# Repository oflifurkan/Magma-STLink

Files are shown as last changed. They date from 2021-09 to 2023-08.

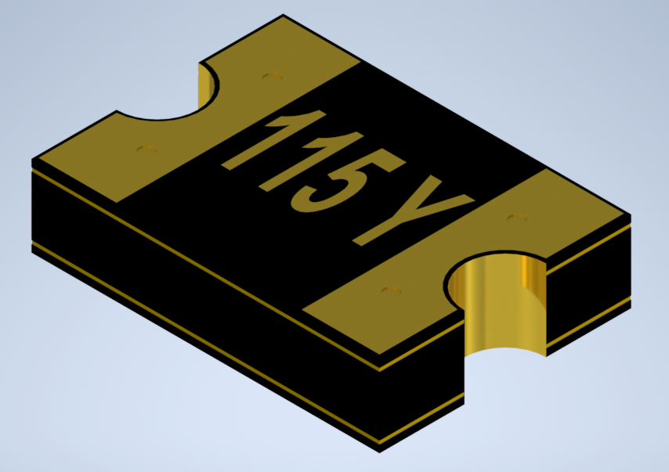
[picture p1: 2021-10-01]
Component Documents/Fuse 1812/smd-1812-pptc-multifuse-mf-1.snapshot.2/smd1812.bmp

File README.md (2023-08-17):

MAGMA STLink
============

STLink V2 design that I designed in KiCAD as a hobby for programming STM32 and STM8 microcontrollers

## What's required? 

* STM32F103C8 - with STLink V2 firmware
* 8 Mhz Crystal

* LM1117 - 5V to 3.3V LDO

* USB A Connector
* PTC Fuse
* Couple of 0805 package capacitors and resistor  

## CAD Software

* The latest KiCAD version

## Images
Magma_STLink_front
Magma_STLink_rear

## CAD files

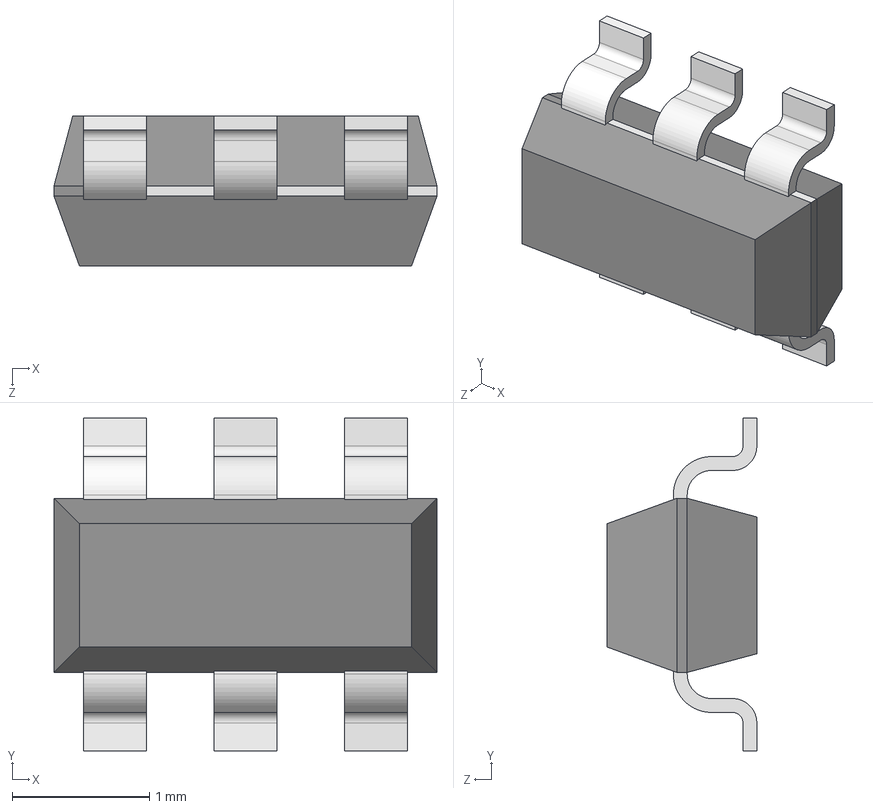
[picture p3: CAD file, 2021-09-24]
Component Documents/ESDA6V1BC6/User Library-SOT-23-6.STEP
2.79 x 2.43 x 1.09 mm

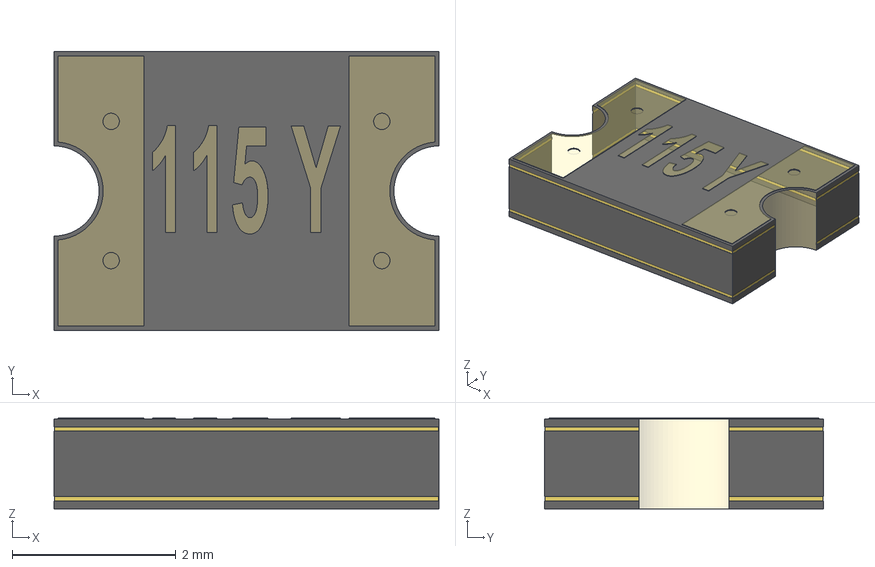
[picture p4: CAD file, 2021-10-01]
Component Documents/Fuse 1812/smd-1812-pptc-multifuse-mf-1.snapshot.2/smd1812.stp
4.70 x 3.40 x 1.11 mm

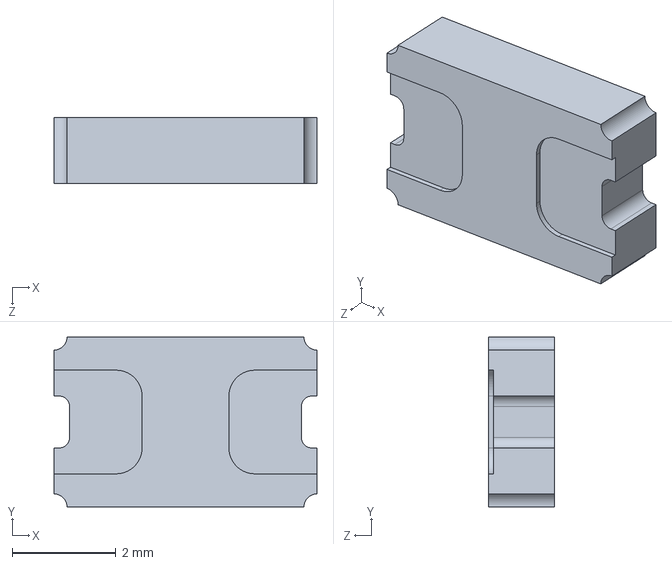
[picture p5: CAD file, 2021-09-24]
Component Documents/TXC 7A/TXC7A.STEP
5.08 x 3.28 x 1.28 mm

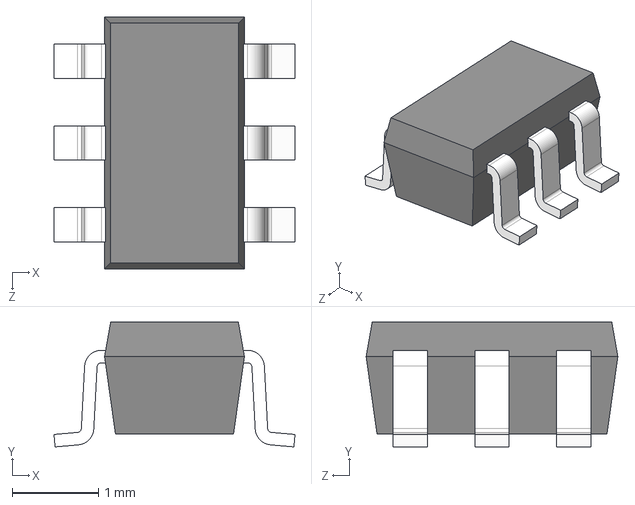
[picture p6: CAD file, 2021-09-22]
Component Documents/ESDA6V1BC6/ESDA6V1BC6.step
2.80 x 1.45 x 2.92 mm

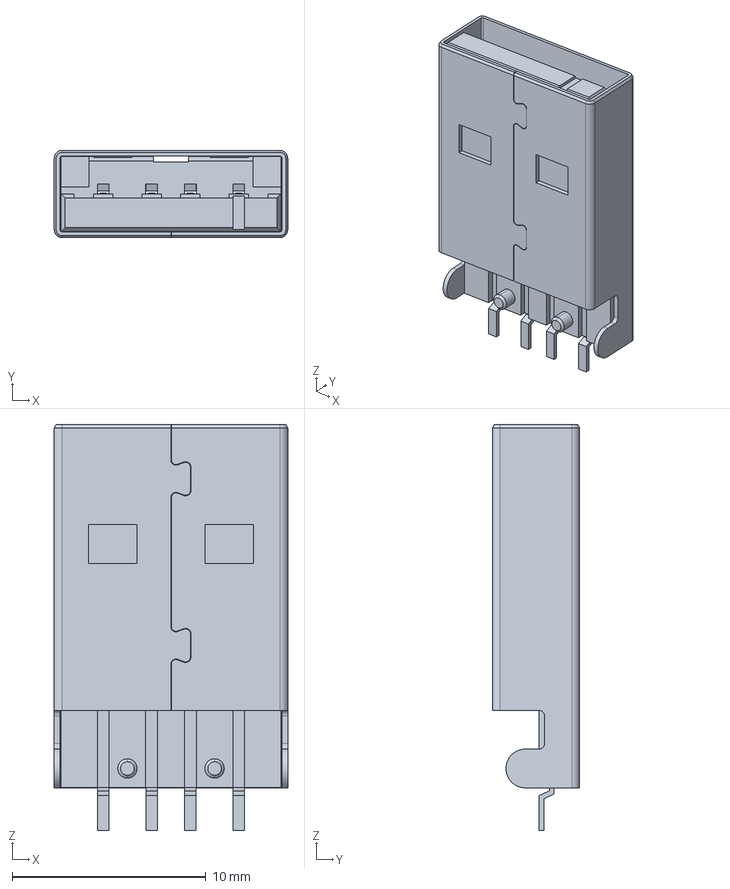
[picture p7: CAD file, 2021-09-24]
Component Documents/USB Type A Male Plug/48037-2200_stp/480372200.stp
12.1 x 4.50 x 21.0 mm

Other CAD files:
Component Documents/TXC 7A/TXC7A.SLDPRT

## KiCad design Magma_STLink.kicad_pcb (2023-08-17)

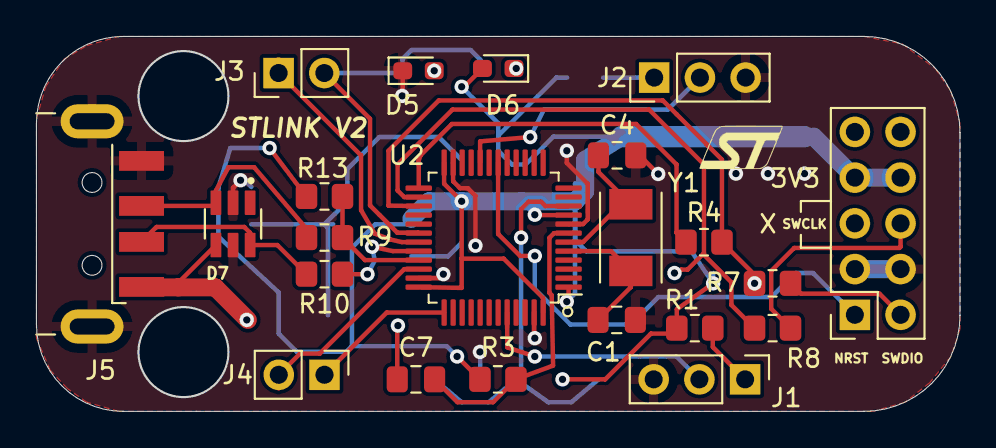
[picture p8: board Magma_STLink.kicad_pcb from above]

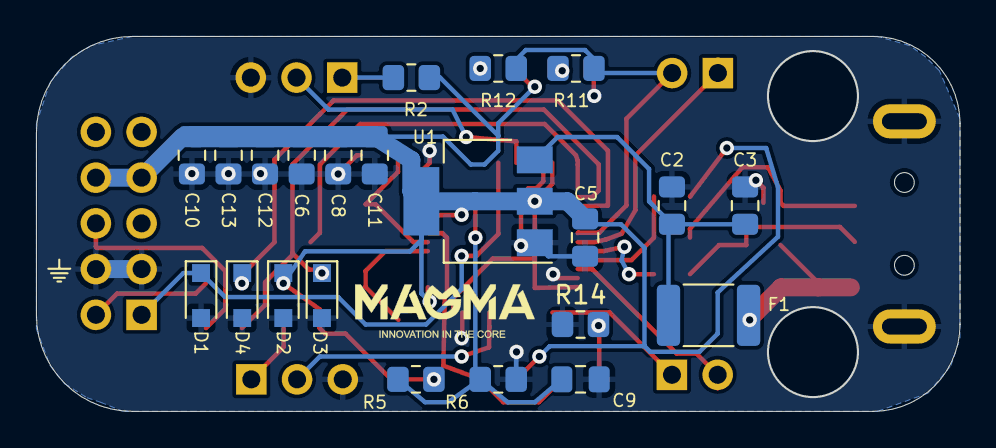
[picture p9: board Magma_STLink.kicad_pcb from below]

Board: 2 copper layers, 51.3 x 20.8 mm, 44 parts (22 on the bottom side), 29 nets.

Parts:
C1, C4: 18pF; C_0805_2012Metric_Pad1.18x1.45mm_HandSolder
C2, C5: 10uF; C_0805_2012Metric_Pad1.18x1.45mm_HandSolder
C3, C6, C7, C8, C9, C10, C11, C12, C13: 100nF; C_0805_2012Metric_Pad1.18x1.45mm_HandSolder
D1, D2, D3, D4: PESD3V3L1BA,115; D_SOD-323_HandSoldering
D5: RED LED; LED_0603_1608Metric_Pad1.05x0.95mm_HandSolder
D6: BLUE RED; LED_0603_1608Metric_Pad1.05x0.95mm_HandSolder
D7: ESDA6V1BC6; SOT95P280X145-6N
F1: 8V 2A; Fuse_1812_4532Metric_Pad1.30x3.40mm_HandSolder
J1, J2: Conn_01x03; PinHeader_1x03_P2.54mm_Vertical
J3, J4: Conn_01x02; PinHeader_1x02_P2.54mm_Vertical
J5: USB_A; USB_A_CNCTech_1001-011-01101_Horizontal
R1, R2: 10K; R_0805_2012Metric_Pad1.20x1.40mm_HandSolder
R3, R5, R6, R13, R14: 100K; R_0805_2012Metric_Pad1.20x1.40mm_HandSolder
R4: 220R; R_0805_2012Metric_Pad1.20x1.40mm_HandSolder
R7, R8, R9, R10: 75R; R_0805_2012Metric_Pad1.20x1.40mm_HandSolder
R11, R12: 200; R_0805_2012Metric_Pad1.20x1.40mm_HandSolder
STLINK_CONN1: STLINK CONN; PinSocket_2x05_P2.54mm_Vertical
U1: LM1117-3.3; SOT-223-3_TabPin2
U2: STM32F103C8Tx; LQFP-48_7x7mm_P0.5mm
Y1: Crystal; Crystal_SMD_TXC_7A-2Pin_5x3.2mm

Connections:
+3V3: C5.1, C6.1, C8.1, C10.1, C11.1, C12.1, C13.1, D2.1, D6.2, R1.2, R2.2, R3.2, R5.1, R13.2, STLINK_CONN1.7, STLINK_CONN1.8, U1.2, U2.1, U2.9, U2.24, U2.36, U2.48
/BOOT0: J1.2, U2.44
/BOOT1: J2.2, U2.20
/NRST: D1.1, STLINK_CONN1.1, U2.18
/OSC_IN: C1.1, U2.5, Y1.1
/OSC_OUT: C4.1, U2.6, Y1.2
/STLINK_SWCLK: D3.1, R8.1, U2.26
/STLINK_SWDIO: D4.1, R4.2, R7.1, U2.27
/SWCLK: J4.1, U2.37
/SWDIO: J4.2, U2.34
/UART_RX: J3.1, U2.31
/UART_TX: J3.2, R11.2, R12.2, U2.30
/USB_N: R10.1, U2.32
/USB_P: R9.1, R13.1, U2.33
GND: C1.2, C2.2, C3.2, C4.2, C5.2, C6.2, C8.2, C9.2, C10.2, C11.2, C12.2, C13.2, D1.2, D2.2, D3.2, D4.2, D5.1, D7.2, D7.5, J1.3, J2.3, J5.4, J5.5, R6.2, R14.1, STLINK_CONN1.3, STLINK_CONN1.4, U1.1, U2.8, U2.23, U2.35, U2.47
unnamed: C2.1, C3.1, F1.2, U1.3
unnamed: C7.1, R3.1, U2.7
unnamed: C7.2, R14.2
unnamed: C9.1, R5.2, R6.1, U2.10
unnamed: D5.2, R11.1
unnamed: D6.1, R12.1
unnamed: D7.3, J5.3, R9.2
unnamed: D7.6, J5.2, R10.2
unnamed: J1.1, R1.1
unnamed: J2.1, R2.1
unnamed: R4.1, U2.25
unnamed: R7.2, STLINK_CONN1.2
unnamed: R8.2, STLINK_CONN1.6
VBUS: D7.4, F1.1, J5.1

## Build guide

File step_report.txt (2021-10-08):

Warning: 14:33:08: [3D File Resolver] No such path; ensure the environment var is defined
Warning: /app/extensions/Library/Packages3D/share/kicad/modules/packages3d//Connector_USB.3dshapes/USB_A_CNCTech_1001-011-01101_Horizontal.wrl
Warning: 14:33:08: /run/build/kicad/utils/kicad2step/pcb/oce_utils.cpp: AddComponent: 588
Warning:   * no model defined for component 'J5'
Warning: 14:33:08: /run/build/kicad/utils/kicad2step/pcb/oce_utils.cpp: AddComponent: 588
Warning:   * no model defined for component 'Y1'
Warning: 14:33:09: /run/build/kicad/utils/kicad2step/pcb/oce_utils.cpp: AddComponent: 588
Warning:   * no model defined for component 'F1'

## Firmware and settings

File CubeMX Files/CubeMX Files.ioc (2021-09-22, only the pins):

Mcu.UserName=STM32F103C8Tx
PA10.Signal=USART1_RX
PA13.Signal=SYS_JTMS-SWDIO
PA14.Signal=SYS_JTCK-SWCLK
PA9.Signal=USART1_TX
PD0-OSC_IN.Signal=RCC_OSC_IN
PD1-OSC_OUT.Signal=RCC_OSC_OUT

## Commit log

2021-09-20 Magma STLink STLink bulunamamasından dolayı Magma STLink yapılması kararlaştırıldı ve başlatıldı.
    [Magma_STLink.kicad_pcb, Magma_STLink.sch]
2021-09-22 STLink şematikleri değiştirildi. Konnektörlerin kararlaştırılması gerekiyor. PCB boyutu önemli. USB ESD koruması eklendi.SWDIO ve SWCLK pinlerine tekli koruma diyotu eklendi.
2021-09-22 Diyot kütüphanesi eklendi.
    [ESDA6V1BC6.step]
2021-09-22 PCB
    PCB'ye geçildi. Boyutları düzeltilerek PCB'ye devam edilecek.
    [Magma_STLink.sch]
2021-09-24 Kütüphane güncellemeleri
    * ESDA6V1BC6 kütüphanesi eklendi.
    * Magma logo oluşturuldu.
    * TXC 7A serisindeki kristal için Enes Ünsal'a step (3 boyutlu model) çizdirildi.
    * USB tip A plug komponentinin step dosyası eklendi.
    [480372200.stp, TXC7A.SLDPRT, TXC7A.STEP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]
2021-09-24 PCB tamamlandı * PCB tamamlandı ve şematikte küçük değişiklikler yapıldı. * DRC yapıldı herhangi bir hata çıkmadı.
    [Magma_STLink.sch]
2021-10-01 Reset'e bir direnç eklendi. Anlık resetleyebilmek için 0805 kılıfında bir direnç eklendi.
    [Magma_STLink-B_Cu.gbl, Magma_STLink-B_Cu.gbr, Magma_STLink-B_Mask.gbr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]
2021-10-08 Son Değişiklikler ve step
    [Magma_STLink-B_Cu.gbl, Magma_STLink-B_Cu.gbr, Magma_STLink-B_Mask.gbr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]
2023-08-17 Update project to latest KiCAD version
    [Magma_STLink.kicad_pcb, Magma_STLink.kicad_sch, Magma_STLink.sch]
